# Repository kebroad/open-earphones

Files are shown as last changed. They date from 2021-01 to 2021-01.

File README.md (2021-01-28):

# Open Earphones

Open Source Modular Earphones that will last a lifetime if you build/fix them yourself.

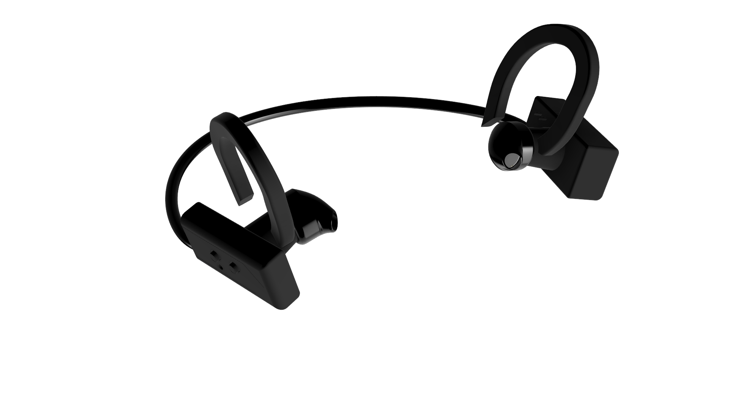
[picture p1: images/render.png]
3D Rendering


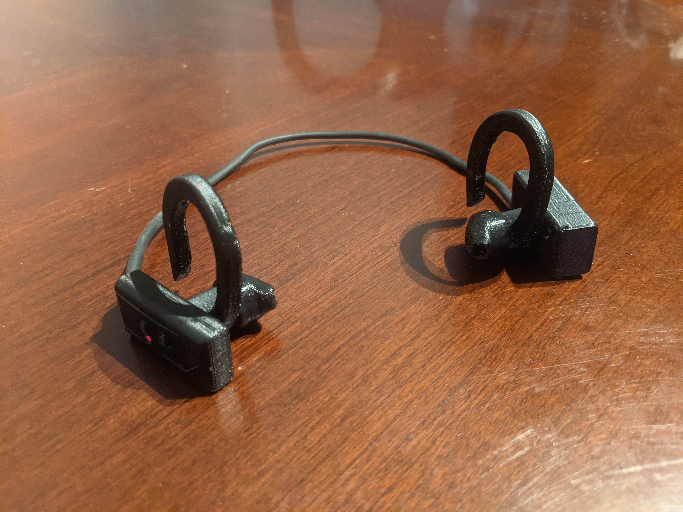
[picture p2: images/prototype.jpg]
Prototype


After spending years buying earphones that would either break or have the battery die, I wanted to build my own pair from scratch in order to be able to repair or replace parts on it easily. Based off of Microchip's IS2083 chip and module, I prototyped custom circuit boards along with 3D printing the case in ABS and the ear-bud tips in flexible TPU.

CAD Files and  PCB files are available in this repo. BOM and a tutorial on how to put assemble them is coming soon.

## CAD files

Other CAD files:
cad-files/Open Earphones v18.f3z

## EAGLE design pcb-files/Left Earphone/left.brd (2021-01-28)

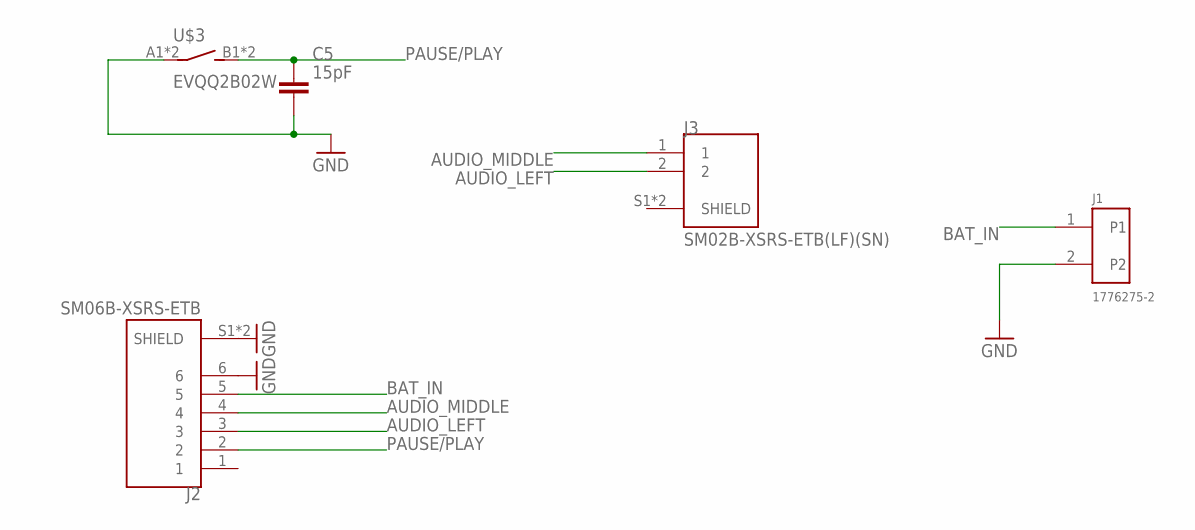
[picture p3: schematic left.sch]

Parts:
C5: 15pF; CAPC2012X110
J1: 1776275-2; TE_1776275-2
J2: SM06B-XSRS-ETB; JST_SM06B-XSRS-ETB
J3: SM02B-XSRS-ETB(LF)(SN); JST_SM02B-XSRS-ETB(LF)(SN)
U$3: EVQQ2B02W

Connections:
AUDIO_LEFT: J2.3, J3.2
AUDIO_MIDDLE: J2.4, J3.1
BAT_IN: J1.1, J2.5
GND: C5.2, J1.2, J2.6, J2.S1 (SHIELD), J2.S2 (SHIELD), U$3.A1, U$3.A2
PAUSE/PLAY: C5.1, J2.2, U$3.B1 (S), U$3.B2 (S)

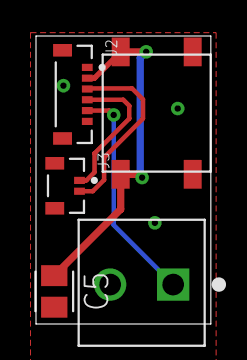
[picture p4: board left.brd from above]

Board: 2 copper layers, 9.7 x 16.0 mm, 5 parts (0 on the bottom side), 5 nets.

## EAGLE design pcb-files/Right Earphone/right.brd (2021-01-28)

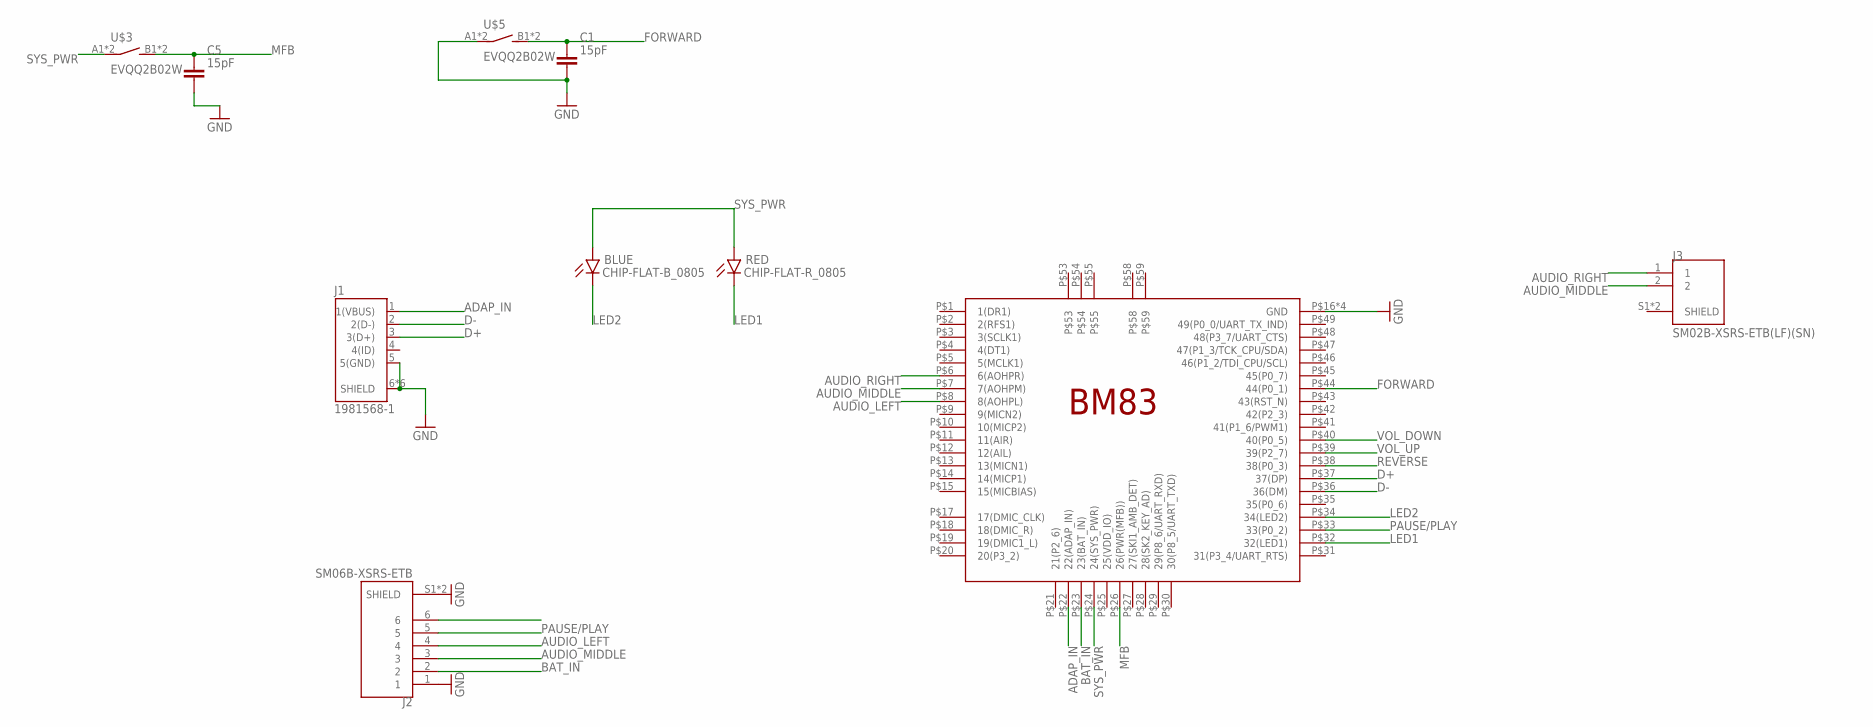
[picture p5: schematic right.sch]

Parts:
BLUE: CHIP-FLAT-B_0805; LEDC2012X110N
C1, C5: 15pF; CAPC2012X110
J1: 1981568-1; TE_1981568-1
J2: SM06B-XSRS-ETB; JST_SM06B-XSRS-ETB
J3: SM02B-XSRS-ETB(LF)(SN); JST_SM02B-XSRS-ETB(LF)(SN)
RED: CHIP-FLAT-R_0805; LEDC2012X110N
U$1: BM83
U$3, U$5: EVQQ2B02W

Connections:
ADAP_IN: J1.1 (1(VBUS)), U$1.P$22 (22(ADAP_IN))
AUDIO_LEFT: J2.4, U$1.P$8 (8(AOHPL))
AUDIO_MIDDLE: J2.3, J3.2, U$1.P$7 (7(AOHPM))
AUDIO_RIGHT: J3.1, U$1.P$6 (6(AOHPR))
BAT_IN: J2.2, U$1.P$23 (23(BAT_IN))
D+: J1.3 (3(D+)), U$1.P$37 (37(DP))
D-: J1.2 (2(D-)), U$1.P$36 (36(DM))
FORWARD: C1.1, U$1.P$44 (44(P0_1)), U$5.B1 (S), U$5.B2 (S)
GND: C1.2, C5.2, J1.5 (5(GND)), J1.6 (SHIELD), J1.7 (SHIELD), J1.8 (SHIELD), J1.9 (SHIELD), J1.10 (SHIELD), J1.11 (SHIELD), J2.1, J2.S1 (SHIELD), J2.S2 (SHIELD), U$1.P$16 (GND), U$1.P$50 (GND), U$1.P$56 (GND), U$1.P$57 (GND), U$5.A1, U$5.A2
LED1: RED.C, U$1.P$32 (32(LED1))
LED2: BLUE.C, U$1.P$34 (34(LED2))
MFB: C5.1, U$1.P$26 (26(PWR(MFB))), U$3.B1 (S), U$3.B2 (S)
PAUSE/PLAY: J2.5, U$1.P$33 (33(P0_2))
REVERSE: U$1.P$38 (38(P0_3))
SYS_PWR: BLUE.A, RED.A, U$1.P$24 (24(SYS_PWR)), U$3.A1, U$3.A2
VOL_DOWN: U$1.P$40 (40(P0_5))
VOL_UP: U$1.P$39 (39(P2_7))

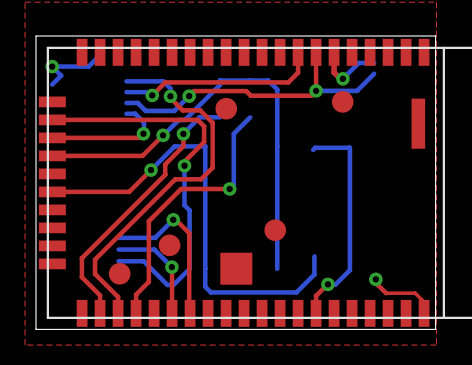
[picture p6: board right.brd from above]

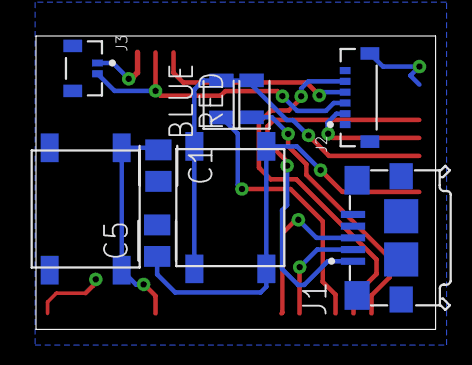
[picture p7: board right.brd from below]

Board: 2 copper layers, 22.2 x 16.3 mm, 10 parts (9 on the bottom side), 14 nets.
